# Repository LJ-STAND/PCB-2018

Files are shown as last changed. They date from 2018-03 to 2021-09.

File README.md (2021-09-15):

# PCB 2018

This repository contains the PCB design files for the LJ STAND 2018 robot. They were produced using Autodesk EAGLE.

**There are the following boards in the ```LJ STAND``` directory:**
- Encoder - this is a hall-sensor based encoder for the robot wheels. Each wheel has alternating polarity magnets that trigger the sensors.
- Gyro MPU9250 - this is a breakout board for a fusion of 3 MPU9250 sensors. This was done to compensate for drift
- Gyro - an older design of the IMU breakout board using a different sensor
- Laser Mount - mount for the laser in a light-gate module
- Light - a 48-sensor circular reflective-light sensor array, used for detecting the position of a white line
- Main - main processing board, housing the microcontrollers, camera, power supply, motor driver modules and IR sensors for the ball
- MPU9250 Adapter - can replace the IMU breakout board with a single off the shelf MPU9250 breakout
- Phototransitor Mount - mount for the phototransistor in a light-gate module

---------------------------------

<p align="center">
  
</p>

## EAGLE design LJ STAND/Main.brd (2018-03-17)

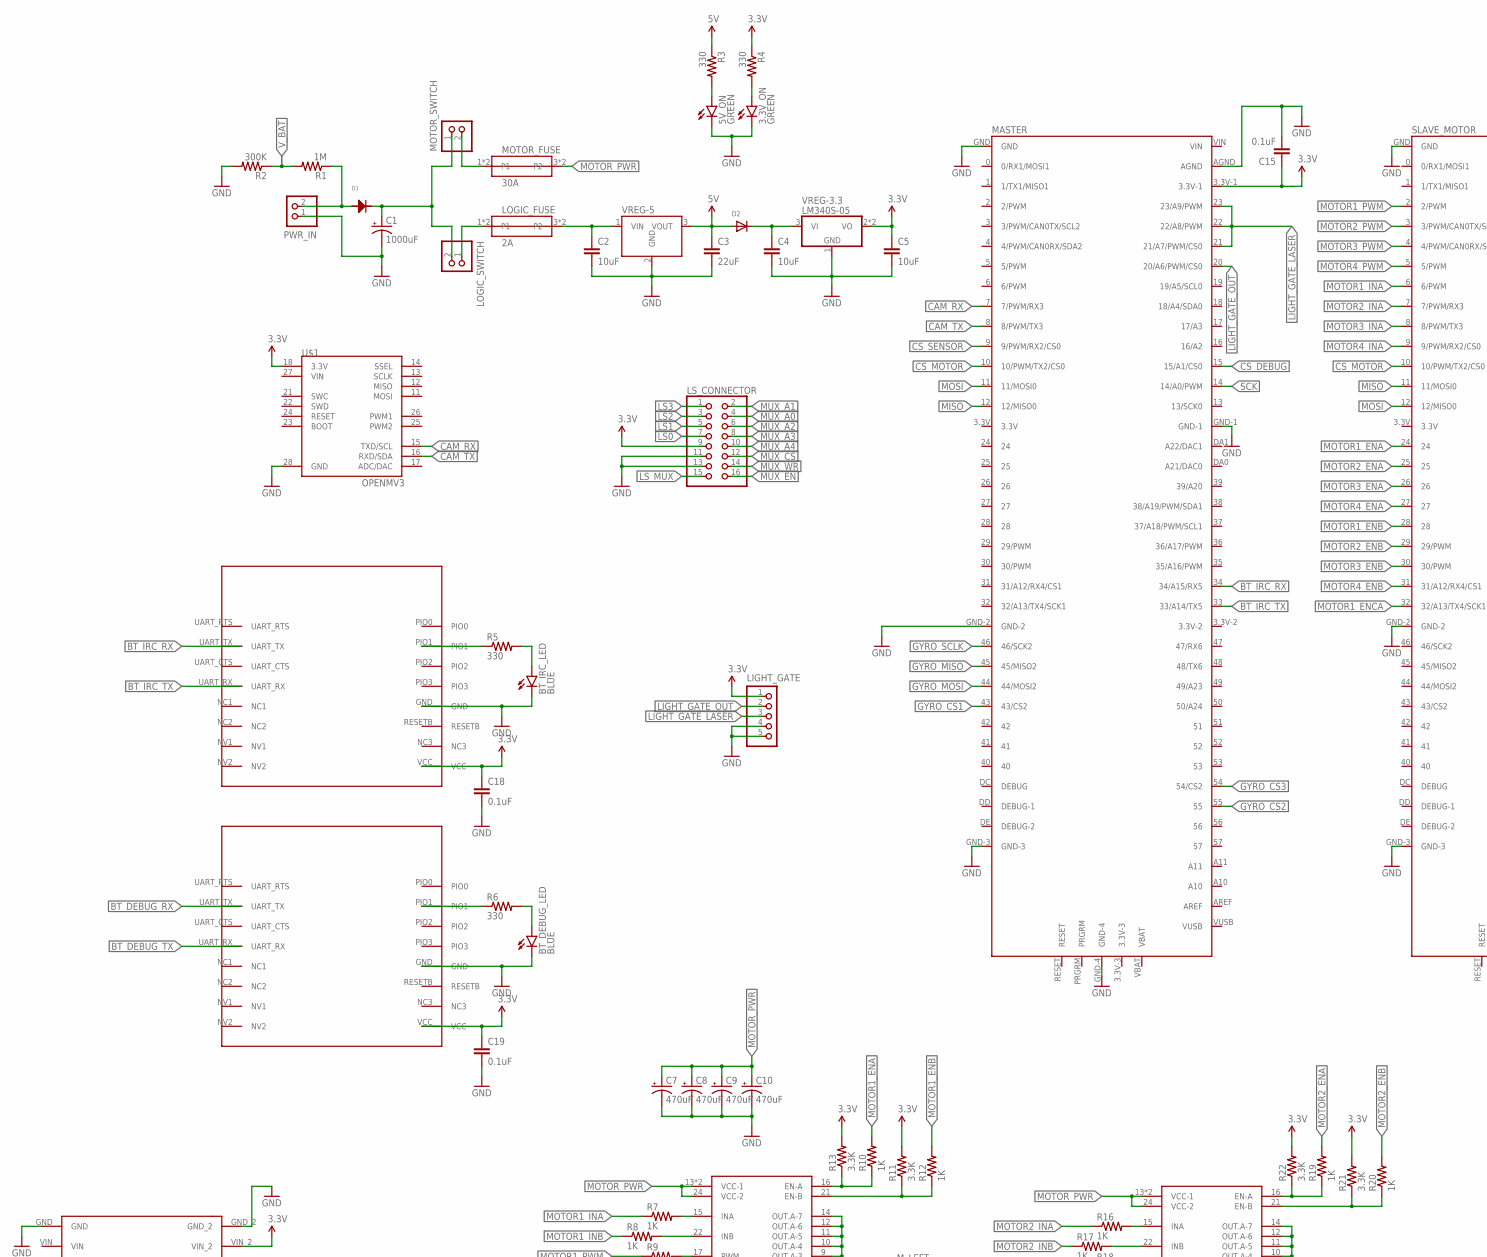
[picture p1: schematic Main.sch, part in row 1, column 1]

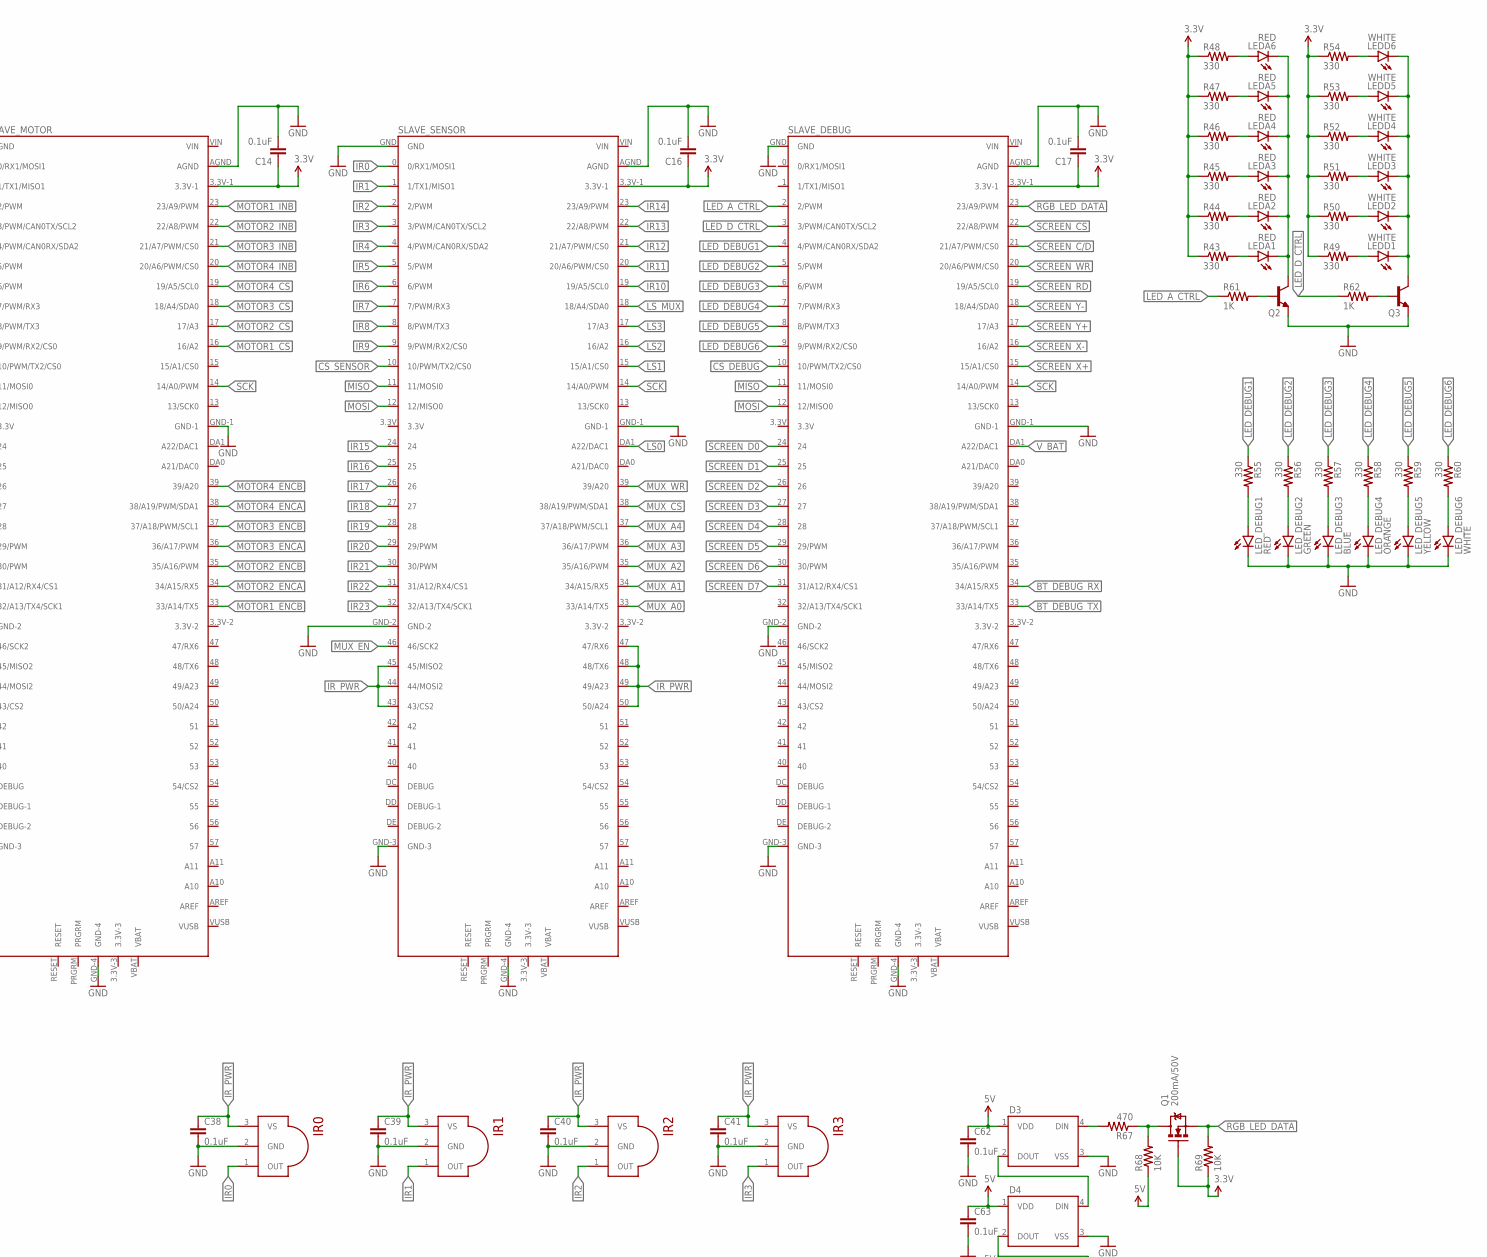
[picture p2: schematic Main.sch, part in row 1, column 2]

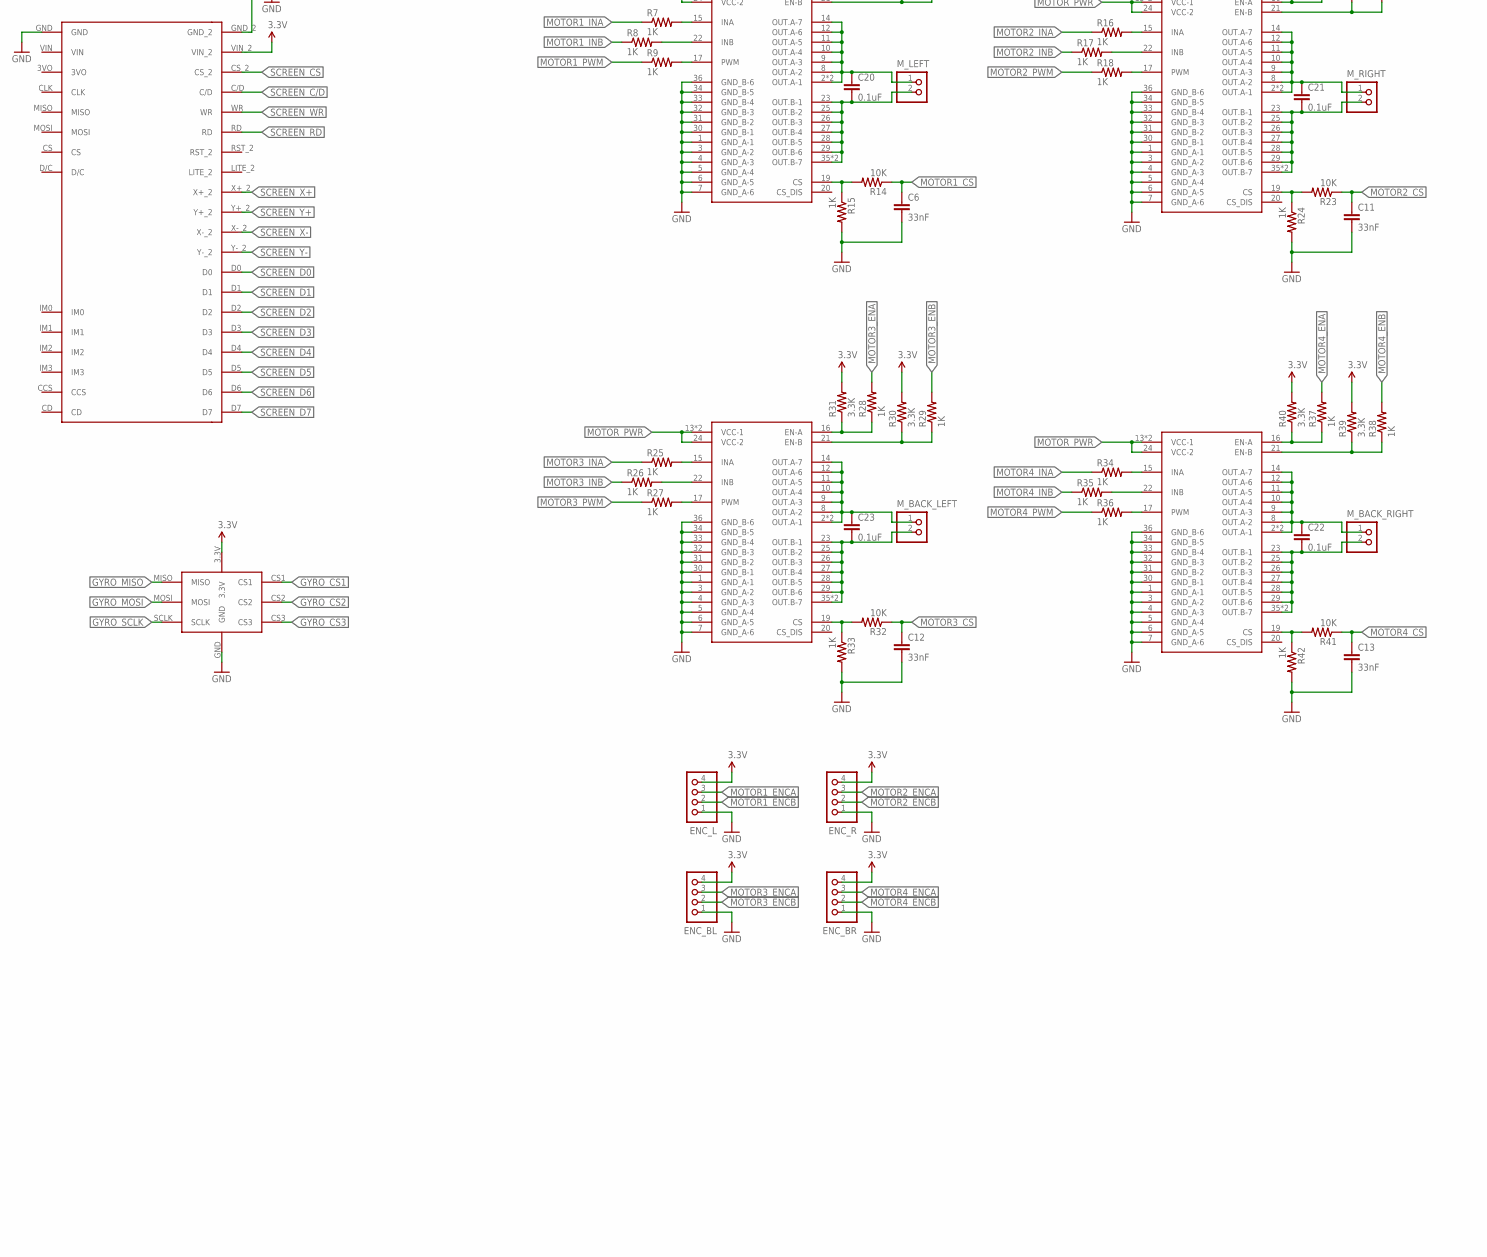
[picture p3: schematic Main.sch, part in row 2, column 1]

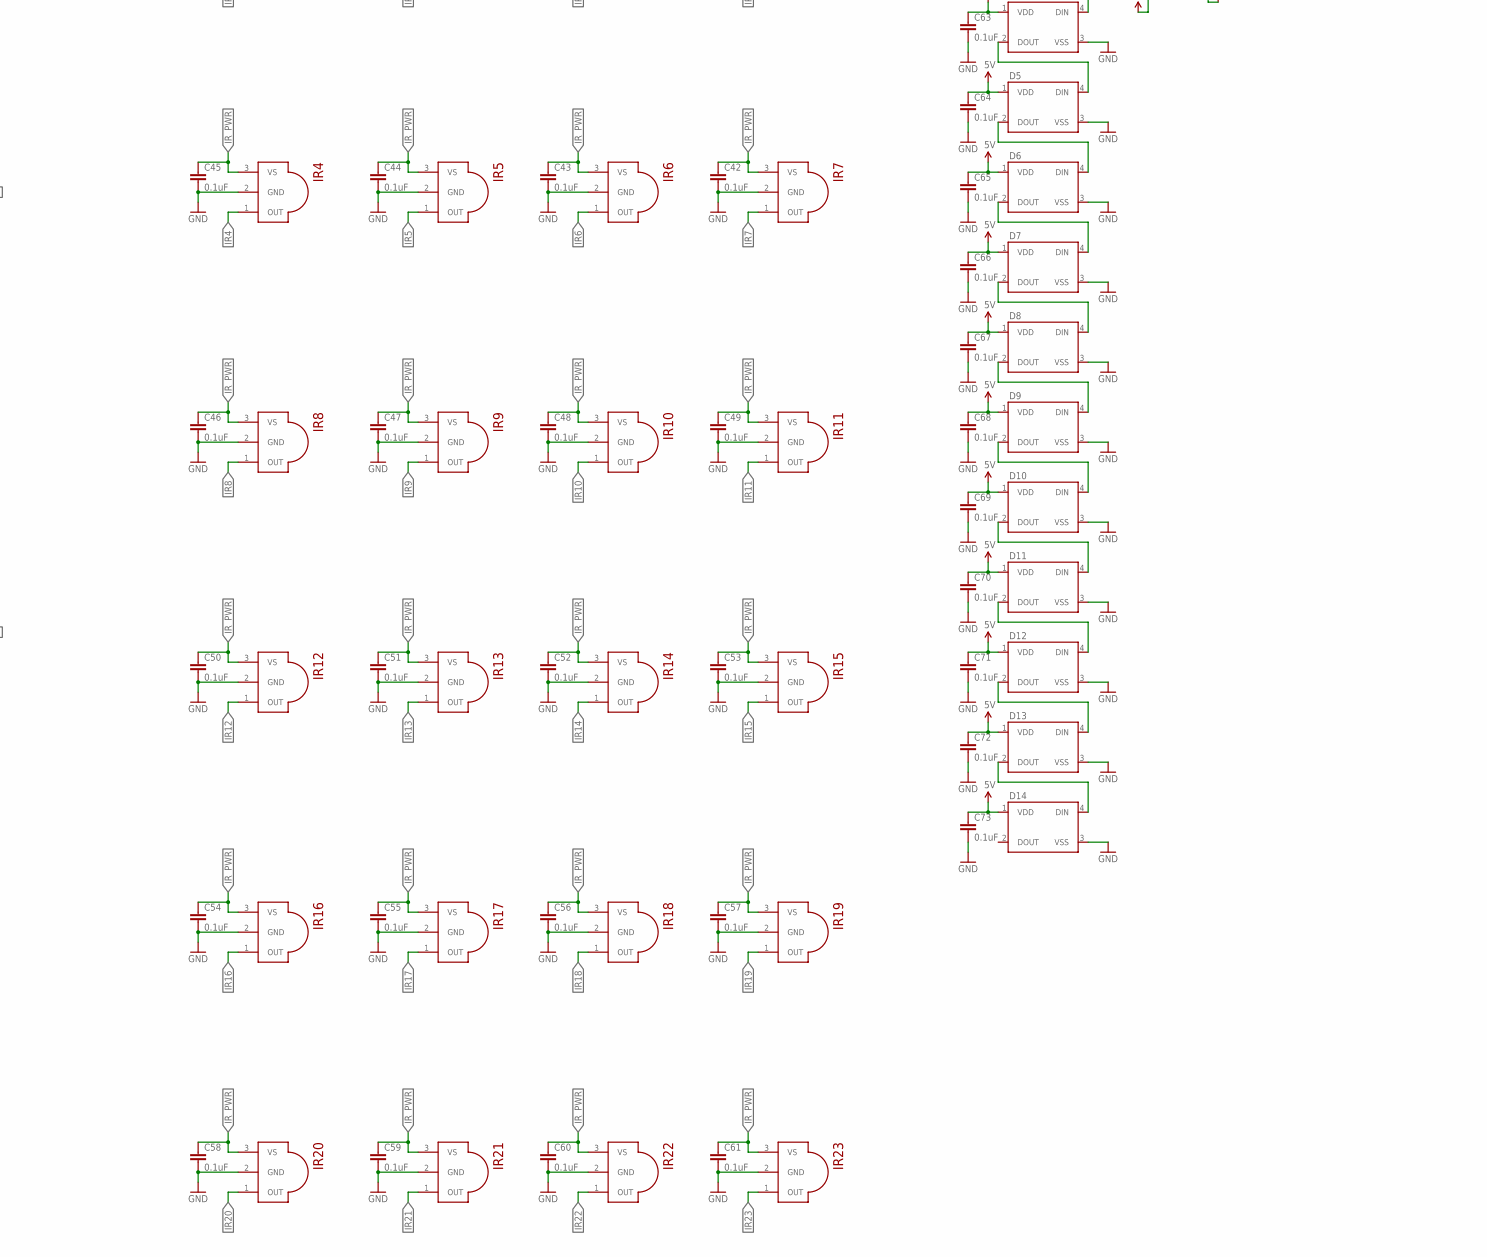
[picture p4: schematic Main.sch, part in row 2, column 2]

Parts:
3.3V_ON, 5V_ON: GREEN; LED-0603
BT_DEBUG: HM-11
BT_DEBUG_LED: BLUE; LED-0603
BT_IRC: HM-11
BT_IRC_LED: BLUE; LED-0603
C1: 1000uF; CPOL-RADIAL-1000UF-25V
C2, C4, C5: 10uF; 0805
C3: 22uF; 1206
C6, C11, C12, C13: 33nF; 0603-CAP
C7, C8, C9, C10: 470uF; E3,5-8
C14, C15, C16, C17, C18, C19, C20, C21, C22, C23, C38, C39, C40, C41, C42, C43, C44, C45, C46, C47, C48, C49, C50, C51, C52, C53, C54, C55, C56, C57, C58, C59, C60, C61, C62, C63, C64, C65, C66, C67, C68, C69, C70, C71, C72, C73: 0.1uF; 0603-CAP
D1: DIODE_D2PAK(TO-263AB); D2PAK(TO-263AB)
D2: DIODE_SOD-123FL; SOD-123FL
D3, D4, D5, D6, D7, D8, D9, D10, D11, D12, D13, D14: WS2812B
ENC_BL: B4B-PH-K-S
ENC_BR: B4B-PH-K-S
ENC_L: B4B-PH-K-S
ENC_R: B4B-PH-K-S
IR0, IR1, IR2, IR3, IR4, IR5, IR6, IR7, IR8, IR9, IR10, IR11, IR12, IR13, IR14, IR15, IR16, IR17, IR18, IR19, IR20, IR21, IR22, IR23: TSSP58038
LEDA1, LEDA2, LEDA3, LEDA4, LEDA5, LEDA6: RED; LED-0603
LEDD1, LEDD2, LEDD3, LEDD4, LEDD5, LEDD6: WHITE; LED-0603
LED_DEBUG1: RED; LED-0603
LED_DEBUG2: GREEN; LED-0603
LED_DEBUG3: BLUE; LED-0603
LED_DEBUG4: ORANGE; LED-0603
LED_DEBUG5: YELLOW; LED-0603
LED_DEBUG6: WHITE; LED-0603
LIGHT_GATE: B5B-PH-K-S
LOGIC_FUSE: 2A; 3568-FUSEHOLDER
LOGIC_SWITCH: B2P-VH
LS_CONNECTOR: PINHD-2X8SMT; 2X08_SMT
MASTER: TEENSY-3.5
MOTOR_FUSE: 30A; 3568-FUSEHOLDER
MOTOR_SWITCH: B2P-VH
M_BACK_LEFT: B2P-VH
M_BACK_RIGHT: B2P-VH
M_LEFT: B2P-VH
M_RIGHT: B2P-VH
P1, P2, P3, P4: SOP50P1030X247-36N
PWR_IN: B2P-VH
Q1: 200mA/50V; SOT23-3
Q2, Q3: TRANSISTOR_NPNSOT23-3; SOT23-3
R1: 1M; 0603-RES
R2: 300K; 0603-RES
R3, R4, R5, R6, R43, R44, R45, R46, R47, R48, R49, R50, R51, R52, R53, R54, R55, R56, R57, R58, R59, R60: 330; 0603-RES
R7, R8, R9, R10, R12, R15, R16, R17, R18, R19, R20, R24, R25, R26, R27, R28, R29, R33, R34, R35, R36, R37, R38, R42, R61, R62: 1K; 0603-RES
R11, R13, R21, R22, R30, R31, R39, R40: 3.3K; 0603-RES
R14, R23, R32, R41, R68, R69: 10K; 0603-RES
R67: 470; 0603-RES
SCREEN: ADAFRUIT-2.4-TFT
SLAVE_DEBUG: TEENSY-3.5
SLAVE_MOTOR: TEENSY-3.5
SLAVE_SENSOR: TEENSY-3.5
U$1: OPENMV3
U$2: GYRO
VREG-3.3: LM340S-05; TO263-3
VREG-5: V78-2000

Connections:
3.3V: BT_DEBUG.VCC, BT_IRC.VCC, C5.1, C14.1, C15.1, C16.1, C17.1, C18.1, C19.1, ENC_BL.4, ENC_BR.4, ENC_L.4, ENC_R.4, LIGHT_GATE.1, LS_CONNECTOR.9, MASTER.3.3V-1, Q1.1 (G), R4.1, R11.2, R13.2, R21.2, R22.2, R30.2, R31.2, R39.2, R40.2, R43.1, R44.1, R45.1, R46.1, R47.1, R48.1, R49.1, R50.1, R51.1, R52.1, R53.1, R54.1, R69.1, SCREEN.VIN_2, SLAVE_DEBUG.3.3V-1, SLAVE_MOTOR.3.3V-1, SLAVE_SENSOR.3.3V-1, U$1.18 (3.3V), U$2.3.3V, VREG-3.3.2 (VO), VREG-3.3.TAB (VO)
5V: C3.1, C62.1, C63.1, C64.1, C65.1, C66.1, C67.1, C68.1, C69.1, C70.1, C71.1, C72.1, C73.1, D2.A, D3.1 (VDD), D4.1 (VDD), D5.1 (VDD), D6.1 (VDD), D7.1 (VDD), D8.1 (VDD), D9.1 (VDD), D10.1 (VDD), D11.1 (VDD), D12.1 (VDD), D13.1 (VDD), D14.1 (VDD), R3.1, R68.1, VREG-5.3 (VOUT)
BT_DEBUG_RX: BT_DEBUG.UART_TX, SLAVE_DEBUG.34 (34/A15/RX5)
BT_DEBUG_TX: BT_DEBUG.UART_RX, SLAVE_DEBUG.33 (33/A14/TX5)
BT_IRC_RX: BT_IRC.UART_TX, MASTER.34 (34/A15/RX5)
BT_IRC_TX: BT_IRC.UART_RX, MASTER.33 (33/A14/TX5)
CAM_RX: MASTER.7 (7/PWM/RX3), U$1.15 (TXD/SCL)
CAM_TX: MASTER.8 (8/PWM/TX3), U$1.16 (RXD/SDA)
CS_DEBUG: MASTER.15 (15/A1/CS0), SLAVE_DEBUG.10 (10/PWM/TX2/CS0)
CS_MOTOR: MASTER.10 (10/PWM/TX2/CS0), SLAVE_MOTOR.10 (10/PWM/TX2/CS0)
CS_SENSOR: MASTER.9 (9/PWM/RX2/CS0), SLAVE_SENSOR.10 (10/PWM/TX2/CS0)
GND: 3.3V_ON.C, 5V_ON.C, BT_DEBUG.GND, BT_DEBUG_LED.C, BT_IRC.GND, BT_IRC_LED.C, C1.-, C2.2, C3.2, C4.2, C5.2, C6.2, C7.-, C8.-, C9.-, C10.-, C11.2, C12.2, C13.2, C14.2, C15.2, C16.2, C17.2, C18.2, C19.2, C38.2, C39.2, C40.2, C41.2, C42.2, C43.2, C44.2, C45.2, C46.2, C47.2, C48.2, C49.2, C50.2, C51.2, C52.2, C53.2, C54.2, C55.2, C56.2, C57.2, C58.2, C59.2, C60.2, C61.2, C62.2, C63.2, C64.2, C65.2, C66.2, C67.2, C68.2, C69.2, C70.2, C71.2, C72.2, C73.2, D3.3 (VSS), D4.3 (VSS), D5.3 (VSS), D6.3 (VSS), D7.3 (VSS), D8.3 (VSS), D9.3 (VSS), D10.3 (VSS), D11.3 (VSS), D12.3 (VSS), D13.3 (VSS), D14.3 (VSS), ENC_BL.1, ENC_BR.1, ENC_L.1, ENC_R.1, IR0.2 (GND), IR1.2 (GND), IR2.2 (GND), IR3.2 (GND), IR4.2 (GND), IR5.2 (GND), IR6.2 (GND), IR7.2 (GND), IR8.2 (GND), IR9.2 (GND), IR10.2 (GND), IR11.2 (GND), IR12.2 (GND), IR13.2 (GND), IR14.2 (GND), IR15.2 (GND), IR16.2 (GND), IR17.2 (GND), IR18.2 (GND), IR19.2 (GND), IR20.2 (GND), IR21.2 (GND), IR22.2 (GND), IR23.2 (GND), LED_DEBUG1.C, LED_DEBUG2.C, LED_DEBUG3.C, LED_DEBUG4.C, LED_DEBUG5.C, LED_DEBUG6.C, LIGHT_GATE.4, LIGHT_GATE.5, LS_CONNECTOR.11, LS_CONNECTOR.13, MASTER.AGND, MASTER.GND, MASTER.GND-1, MASTER.GND-2, MASTER.GND-3, MASTER.GND-4, P1.1 (GND_A-1), P1.3 (GND_A-2), P1.4 (GND_A-3), P1.5 (GND_A-4), P1.6 (GND_A-5), P1.7 (GND_A-6), P1.30 (GND_B-1), P1.31 (GND_B-2), P1.32 (GND_B-3), P1.33 (GND_B-4), P1.34 (GND_B-5), P1.36 (GND_B-6), P2.1 (GND_A-1), P2.3 (GND_A-2), P2.4 (GND_A-3), P2.5 (GND_A-4), P2.6 (GND_A-5), P2.7 (GND_A-6), P2.30 (GND_B-1), P2.31 (GND_B-2), P2.32 (GND_B-3), P2.33 (GND_B-4), P2.34 (GND_B-5), P2.36 (GND_B-6), P3.1 (GND_A-1), P3.3 (GND_A-2), P3.4 (GND_A-3), P3.5 (GND_A-4), P3.6 (GND_A-5), P3.7 (GND_A-6), P3.30 (GND_B-1), P3.31 (GND_B-2), P3.32 (GND_B-3), P3.33 (GND_B-4), P3.34 (GND_B-5), P3.36 (GND_B-6), P4.1 (GND_A-1), P4.3 (GND_A-2), P4.4 (GND_A-3), P4.5 (GND_A-4), P4.6 (GND_A-5), P4.7 (GND_A-6), P4.30 (GND_B-1), P4.31 (GND_B-2), P4.32 (GND_B-3), P4.33 (GND_B-4), P4.34 (GND_B-5), P4.36 (GND_B-6), PWR_IN.1, Q2.2 (E), Q3.2 (E), R2.2, R15.2, R24.2, R33.2, R42.2, SCREEN.GND, SCREEN.GND_2, SLAVE_DEBUG.AGND, SLAVE_DEBUG.GND, SLAVE_DEBUG.GND-1, SLAVE_DEBUG.GND-2, SLAVE_DEBUG.GND-3, SLAVE_DEBUG.GND-4, SLAVE_MOTOR.AGND, SLAVE_MOTOR.GND, SLAVE_MOTOR.GND-1, SLAVE_MOTOR.GND-2, SLAVE_MOTOR.GND-3, SLAVE_MOTOR.GND-4, SLAVE_SENSOR.AGND, SLAVE_SENSOR.GND, SLAVE_SENSOR.GND-1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
GYRO_CS1: MASTER.43 (43/CS2), U$2.CS1
GYRO_CS2: MASTER.55, U$2.CS2
GYRO_CS3: MASTER.54 (54/CS2), U$2.CS3
GYRO_MISO: MASTER.45 (45/MISO2), U$2.MISO
GYRO_MOSI: MASTER.44 (44/MOSI2), U$2.MOSI
GYRO_SCLK: MASTER.46 (46/SCK2), U$2.SCLK
IR0: IR0.1 (OUT), SLAVE_SENSOR.0 (0/RX1/MOSI1)
IR1: IR1.1 (OUT), SLAVE_SENSOR.1 (1/TX1/MISO1)
IR2: IR2.1 (OUT), SLAVE_SENSOR.2 (2/PWM)
IR3: IR3.1 (OUT), SLAVE_SENSOR.3 (3/PWM/CAN0TX/SCL2)
IR4: IR4.1 (OUT), SLAVE_SENSOR.4 (4/PWM/CAN0RX/SDA2)
IR5: IR5.1 (OUT), SLAVE_SENSOR.5 (5/PWM)
IR6: IR6.1 (OUT), SLAVE_SENSOR.6 (6/PWM)
IR7: IR7.1 (OUT), SLAVE_SENSOR.7 (7/PWM/RX3)
IR8: IR8.1 (OUT), SLAVE_SENSOR.8 (8/PWM/TX3)
IR9: IR9.1 (OUT), SLAVE_SENSOR.9 (9/PWM/RX2/CS0)
IR10: IR10.1 (OUT), SLAVE_SENSOR.19 (19/A5/SCL0)
IR11: IR11.1 (OUT), SLAVE_SENSOR.20 (20/A6/PWM/CS0)
IR12: IR12.1 (OUT), SLAVE_SENSOR.21 (21/A7/PWM/CS0)
IR13: IR13.1 (OUT), SLAVE_SENSOR.22 (22/A8/PWM)
IR14: IR14.1 (OUT), SLAVE_SENSOR.23 (23/A9/PWM)
IR15: IR15.1 (OUT), SLAVE_SENSOR.24
IR16: IR16.1 (OUT), SLAVE_SENSOR.25
IR17: IR17.1 (OUT), SLAVE_SENSOR.26
IR18: IR18.1 (OUT), SLAVE_SENSOR.27
IR19: IR19.1 (OUT), SLAVE_SENSOR.28
IR20: IR20.1 (OUT), SLAVE_SENSOR.29 (29/PWM)
IR21: IR21.1 (OUT), SLAVE_SENSOR.30 (30/PWM)
IR22: IR22.1 (OUT), SLAVE_SENSOR.31 (31/A12/RX4/CS1)
IR23: IR23.1 (OUT), SLAVE_SENSOR.32 (32/A13/TX4/SCK1)
IR_PWR: C38.1, C39.1, C40.1, C41.1, C42.1, C43.1, C44.1, C45.1, C46.1, C47.1, C48.1, C49.1, C50.1, C51.1, C52.1, C53.1, C54.1, C55.1, C56.1, C57.1, C58.1, C59.1, C60.1, C61.1, IR0.3 (VS), IR1.3 (VS), IR2.3 (VS), IR3.3 (VS), IR4.3 (VS), IR5.3 (VS), IR6.3 (VS), IR7.3 (VS), IR8.3 (VS), IR9.3 (VS), IR10.3 (VS), IR11.3 (VS), IR12.3 (VS), IR13.3 (VS), IR14.3 (VS), IR15.3 (VS), IR16.3 (VS), IR17.3 (VS), IR18.3 (VS), IR19.3 (VS), IR20.3 (VS), IR21.3 (VS), IR22.3 (VS), IR23.3 (VS), SLAVE_SENSOR.43 (43/CS2), SLAVE_SENSOR.44 (44/MOSI2), SLAVE_SENSOR.45 (45/MISO2), SLAVE_SENSOR.47 (47/RX6), SLAVE_SENSOR.48 (48/TX6), SLAVE_SENSOR.49 (49/A23), SLAVE_SENSOR.50 (50/A24)
LED_A_CTRL: R61.1, SLAVE_DEBUG.2 (2/PWM)
LED_DEBUG1: R55.1, SLAVE_DEBUG.4 (4/PWM/CAN0RX/SDA2)
LED_DEBUG2: R56.1, SLAVE_DEBUG.5 (5/PWM)
LED_DEBUG3: R57.1, SLAVE_DEBUG.6 (6/PWM)
LED_DEBUG4: R58.1, SLAVE_DEBUG.7 (7/PWM/RX3)
LED_DEBUG5: R59.1, SLAVE_DEBUG.8 (8/PWM/TX3)
LED_DEBUG6: R60.1, SLAVE_DEBUG.9 (9/PWM/RX2/CS0)
LED_D_CTRL: R62.1, SLAVE_DEBUG.3 (3/PWM/CAN0TX/SCL2)
LIGHT_GATE_LASER: LIGHT_GATE.3, MASTER.21 (21/A7/PWM/CS0), MASTER.22 (22/A8/PWM), MASTER.23 (23/A9/PWM)
LIGHT_GATE_OUT: LIGHT_GATE.2, MASTER.20 (20/A6/PWM/CS0)
LS0: LS_CONNECTOR.7, SLAVE_SENSOR.DA1 (A22/DAC1)
LS1: LS_CONNECTOR.5, SLAVE_SENSOR.15 (15/A1/CS0)
LS2: LS_CONNECTOR.3, SLAVE_SENSOR.16 (16/A2)
LS3: LS_CONNECTOR.1, SLAVE_SENSOR.17 (17/A3)
LS_MUX: LS_CONNECTOR.15, SLAVE_SENSOR.18 (18/A4/SDA0)
MISO: MASTER.12 (12/MISO0), SLAVE_DEBUG.11 (11/MOSI0), SLAVE_MOTOR.11 (11/MOSI0), SLAVE_SENSOR.11 (11/MOSI0)
MOSI: MASTER.11 (11/MOSI0), SLAVE_DEBUG.12 (12/MISO0), SLAVE_MOTOR.12 (12/MISO0), SLAVE_SENSOR.12 (12/MISO0)
MOTOR1_CS: C6.1, R14.1, SLAVE_MOTOR.16 (16/A2)
MOTOR1_ENA: R10.2, SLAVE_MOTOR.24
MOTOR1_ENB: R12.2, SLAVE_MOTOR.28
MOTOR1_ENCA: ENC_L.3, SLAVE_MOTOR.32 (32/A13/TX4/SCK1)
MOTOR1_ENCB: ENC_L.2, SLAVE_MOTOR.33 (33/A14/TX5)
MOTOR1_INA: R7.1, SLAVE_MOTOR.6 (6/PWM)
MOTOR1_INB: R8.1, SLAVE_MOTOR.23 (23/A9/PWM)
MOTOR1_OUTA: C20.1, M_LEFT.1, P1.2 (OUT.A-1), P1.8 (OUT.A-2), P1.9 (OUT.A-3), P1.10 (OUT.A-4), P1.11 (OUT.A-5), P1.12 (OUT.A-6), P1.14 (OUT.A-7), P1.SLUG2 (OUT.A-1)
MOTOR1_OUTB: C20.2, M_LEFT.2, P1.23 (OUT.B-1), P1.25 (OUT.B-2), P1.26 (OUT.B-3), P1.27 (OUT.B-4), P1.28 (OUT.B-5), P1.29 (OUT.B-6), P1.35 (OUT.B-7), P1.SLUG3 (OUT.B-7)
MOTOR1_PWM: R9.1, SLAVE_MOTOR.2 (2/PWM)
MOTOR2_CS: C11.1, R23.1, SLAVE_MOTOR.17 (17/A3)
MOTOR2_ENA: R19.2, SLAVE_MOTOR.25
MOTOR2_ENB: R20.2, SLAVE_MOTOR.29 (29/PWM)
MOTOR2_ENCA: ENC_R.3, SLAVE_MOTOR.34 (34/A15/RX5)
MOTOR2_ENCB: ENC_R.2, SLAVE_MOTOR.35 (35/A16/PWM)
MOTOR2_INA: R16.1, SLAVE_MOTOR.7 (7/PWM/RX3)
MOTOR2_INB: R17.1, SLAVE_MOTOR.22 (22/A8/PWM)
MOTOR2_OUTA: C21.1, M_RIGHT.1, P2.2 (OUT.A-1), P2.8 (OUT.A-2), P2.9 (OUT.A-3), P2.10 (OUT.A-4), P2.11 (OUT.A-5), P2.12 (OUT.A-6), P2.14 (OUT.A-7), P2.SLUG2 (OUT.A-1)
MOTOR2_OUTB: C21.2, M_RIGHT.2, P2.23 (OUT.B-1), P2.25 (OUT.B-2), P2.26 (OUT.B-3), P2.27 (OUT.B-4), P2.28 (OUT.B-5), P2.29 (OUT.B-6), P2.35 (OUT.B-7), P2.SLUG3 (OUT.B-7)
MOTOR2_PWM: R18.1, SLAVE_MOTOR.3 (3/PWM/CAN0TX/SCL2)
MOTOR3_CS: C12.1, R32.1, SLAVE_MOTOR.18 (18/A4/SDA0)
MOTOR3_ENA: R28.2, SLAVE_MOTOR.26
MOTOR3_ENB: R29.2, SLAVE_MOTOR.30 (30/PWM)
MOTOR3_ENCA: ENC_BL.3, SLAVE_MOTOR.36 (36/A17/PWM)
MOTOR3_ENCB: ENC_BL.2, SLAVE_MOTOR.37 (37/A18/PWM/SCL1)
MOTOR3_INA: R25.1, SLAVE_MOTOR.8 (8/PWM/TX3)
MOTOR3_INB: R26.1, SLAVE_MOTOR.21 (21/A7/PWM/CS0)
MOTOR3_OUTA: C23.1, M_BACK_LEFT.1, P3.2 (OUT.A-1), P3.8 (OUT.A-2), P3.9 (OUT.A-3), P3.10 (OUT.A-4), P3.11 (OUT.A-5), P3.12 (OUT.A-6), P3.14 (OUT.A-7), P3.SLUG2 (OUT.A-1)
MOTOR3_OUTB: C23.2, M_BACK_LEFT.2, P3.23 (OUT.B-1), P3.25 (OUT.B-2), P3.26 (OUT.B-3), P3.27 (OUT.B-4), P3.28 (OUT.B-5), P3.29 (OUT.B-6), P3.35 (OUT.B-7), P3.SLUG3 (OUT.B-7)
MOTOR3_PWM: R27.1, SLAVE_MOTOR.4 (4/PWM/CAN0RX/SDA2)
MOTOR4_CS: C13.1, R41.1, SLAVE_MOTOR.19 (19/A5/SCL0)
MOTOR4_ENA: R37.2, SLAVE_MOTOR.27
MOTOR4_ENB: R38.2, SLAVE_MOTOR.31 (31/A12/RX4/CS1)
MOTOR4_ENCA: ENC_BR.3, SLAVE_MOTOR.38 (38/A19/PWM/SDA1)
MOTOR4_ENCB: ENC_BR.2, SLAVE_MOTOR.39 (39/A20)
MOTOR4_INA: R34.1, SLAVE_MOTOR.9 (9/PWM/RX2/CS0)
MOTOR4_INB: R35.1, SLAVE_MOTOR.20 (20/A6/PWM/CS0)
MOTOR4_OUTA: C22.1, M_BACK_RIGHT.1, P4.2 (OUT.A-1), P4.8 (OUT.A-2), P4.9 (OUT.A-3), P4.10 (OUT.A-4), P4.11 (OUT.A-5), P4.12 (OUT.A-6), P4.14 (OUT.A-7), P4.SLUG2 (OUT.A-1)
MOTOR4_OUTB: C22.2, M_BACK_RIGHT.2, P4.23 (OUT.B-1), P4.25 (OUT.B-2), P4.26 (OUT.B-3), P4.27 (OUT.B-4), P4.28 (OUT.B-5), P4.29 (OUT.B-6), P4.35 (OUT.B-7), P4.SLUG3 (OUT.B-7)
MOTOR4_PWM: R36.1, SLAVE_MOTOR.5 (5/PWM)
MOTOR_PWR: C7.+, C8.+, C9.+, C10.+, MOTOR_FUSE.3 (P2), MOTOR_FUSE.4 (P2), P1.13 (VCC-1), P1.24 (VCC-2), P1.SLUG1 (VCC-1), P2.13 (VCC-1), P2.24 (VCC-2), P2.SLUG1 (VCC-1), P3.13 (VCC-1), P3.24 (VCC-2), P3.SLUG1 (VCC-1), P4.13 (VCC-1), P4.24 (VCC-2), P4.SLUG1 (VCC-1)
MUX_A0: LS_CONNECTOR.4, SLAVE_SENSOR.33 (33/A14/TX5)
MUX_A1: LS_CONNECTOR.2, SLAVE_SENSOR.34 (34/A15/RX5)
MUX_A2: LS_CONNECTOR.6, SLAVE_SENSOR.35 (35/A16/PWM)
MUX_A3: LS_CONNECTOR.8, SLAVE_SENSOR.36 (36/A17/PWM)
MUX_A4: LS_CONNECTOR.10, SLAVE_SENSOR.37 (37/A18/PWM/SCL1)
MUX_CS: LS_CONNECTOR.12, SLAVE_SENSOR.38 (38/A19/PWM/SDA1)
MUX_EN: LS_CONNECTOR.16, SLAVE_SENSOR.46 (46/SCK2)
MUX_WR: LS_CONNECTOR.14, SLAVE_SENSOR.39 (39/A20)
unnamed: MOTOR_FUSE.1, MOTOR_FUSE.2 (P1), MOTOR_SWITCH.2
unnamed: LOGIC_FUSE.1, LOGIC_FUSE.2 (P1), LOGIC_SWITCH.1
unnamed: LEDA1.A, R43.2
unnamed: LEDA2.A, R44.2
unnamed: LEDA3.A, R45.2
unnamed: LEDA4.A, R46.2
unnamed: LEDA5.A, R47.2
unnamed: LEDA6.A, R48.2
unnamed: LEDA1.C, LEDA2.C, LEDA3.C, LEDA4.C, LEDA5.C, LEDA6.C, Q2.3 (C)
unnamed: D1.A (ANODE), D1.NOP (ANODE), PWR_IN.2, R1.1
unnamed: C1.+, D1.C (CATHODE), LOGIC_SWITCH.2, MOTOR_SWITCH.1
unnamed: C2.1, LOGIC_FUSE.3 (P2), LOGIC_FUSE.4 (P2), VREG-5.1 (VIN)
unnamed: C4.1, D2.C, VREG-3.3.3 (VI)
unnamed: 5V_ON.A, R3.2
unnamed: 3.3V_ON.A, R4.2
unnamed: BT_IRC_LED.A, R5.2
unnamed: BT_IRC.PIO1, R5.1
unnamed: BT_DEBUG_LED.A, R6.2
unnamed: BT_DEBUG.PIO1, R6.1
unnamed: P1.16 (EN-A), R10.1, R13.1
unnamed: P1.22 (INB), R8.2
unnamed: P1.17 (PWM), R9.2
unnamed: P1.15 (INA), R7.2
unnamed: P1.21 (EN-B), R11.1, R12.1
unnamed: P1.19 (CS), R14.2, R15.1
unnamed: LEDD1.A, R49.2
unnamed: P2.15 (INA), R16.2
unnamed: P2.22 (INB), R17.2
unnamed: P2.17 (PWM), R18.2
unnamed: P2.16 (EN-A), R19.1, R22.1
unnamed: P2.21 (EN-B), R20.1, R21.1
unnamed: P2.19 (CS), R23.2, R24.1
unnamed: P3.15 (INA), R25.2
unnamed: P3.22 (INB), R26.2
unnamed: P3.17 (PWM), R27.2
unnamed: P3.16 (EN-A), R28.1, R31.1
unnamed: P3.21 (EN-B), R29.1, R30.1
unnamed: P3.19 (CS), R32.2, R33.1
unnamed: P4.15 (INA), R34.2
unnamed: P4.22 (INB), R35.2
unnamed: P4.17 (PWM), R36.2
unnamed: P4.16 (EN-A), R37.1, R40.1
unnamed: P4.21 (EN-B), R38.1, R39.1
unnamed: P4.19 (CS), R41.2, R42.1
unnamed: LEDD2.A, R50.2
unnamed: LEDD3.A, R51.2
unnamed: LEDD4.A, R52.2
unnamed: LEDD5.A, R53.2
unnamed: LEDD6.A, R54.2
unnamed: LEDD1.C, LEDD2.C, LEDD3.C, LEDD4.C, LEDD5.C, LEDD6.C, Q3.3 (C)
unnamed: LED_DEBUG1.A, R55.2
unnamed: LED_DEBUG2.A, R56.2
unnamed: LED_DEBUG3.A, R57.2
unnamed: LED_DEBUG4.A, R58.2
unnamed: LED_DEBUG5.A, R59.2
unnamed: LED_DEBUG6.A, R60.2
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

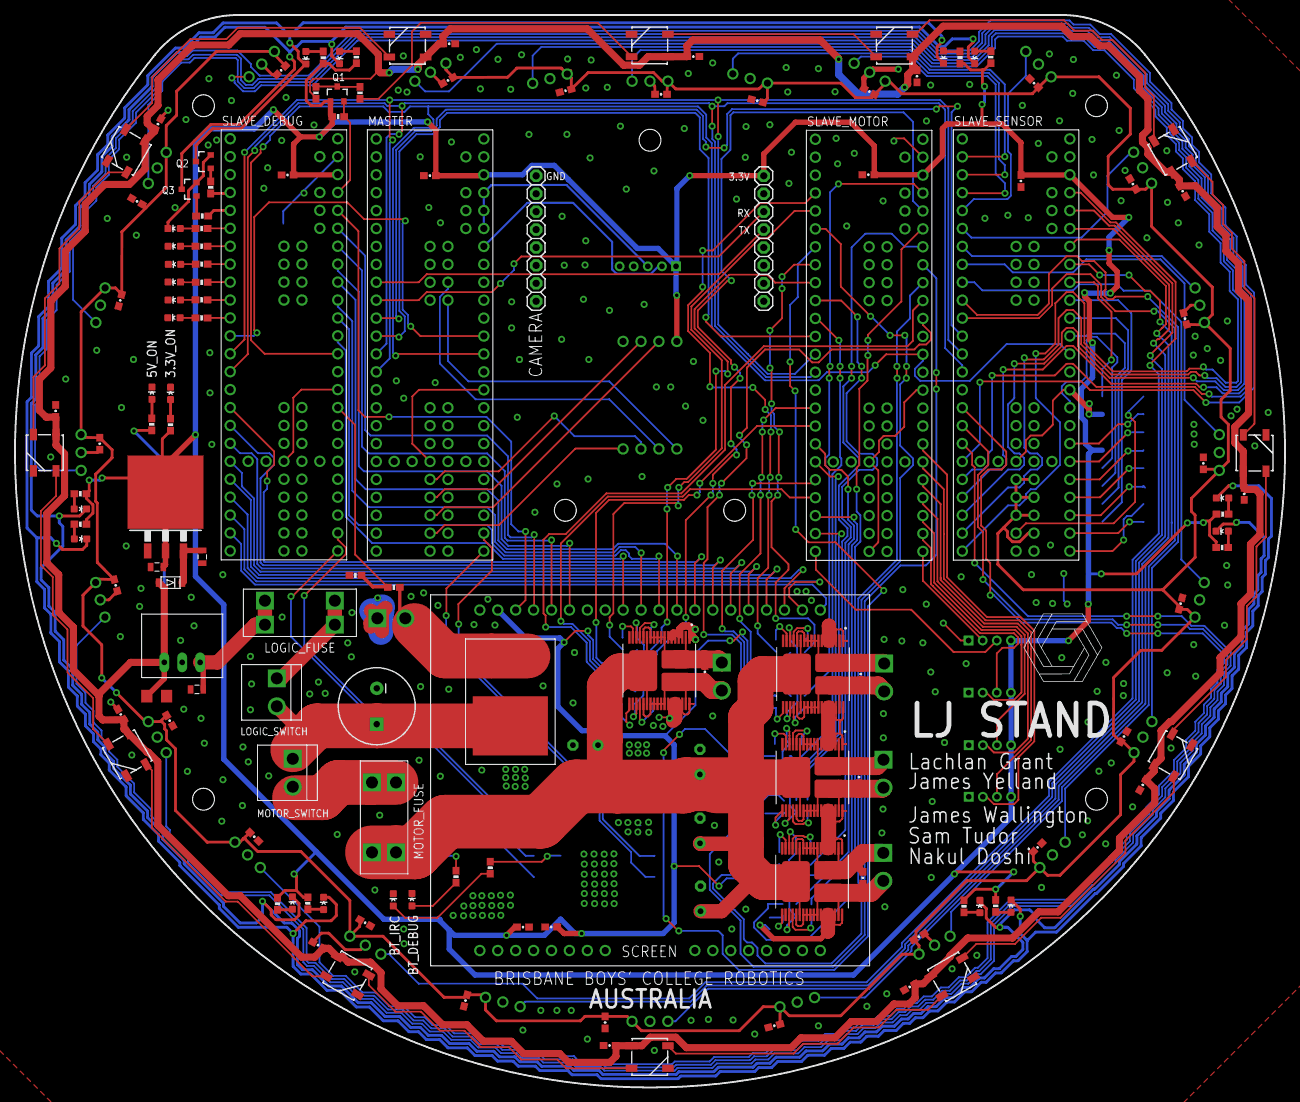
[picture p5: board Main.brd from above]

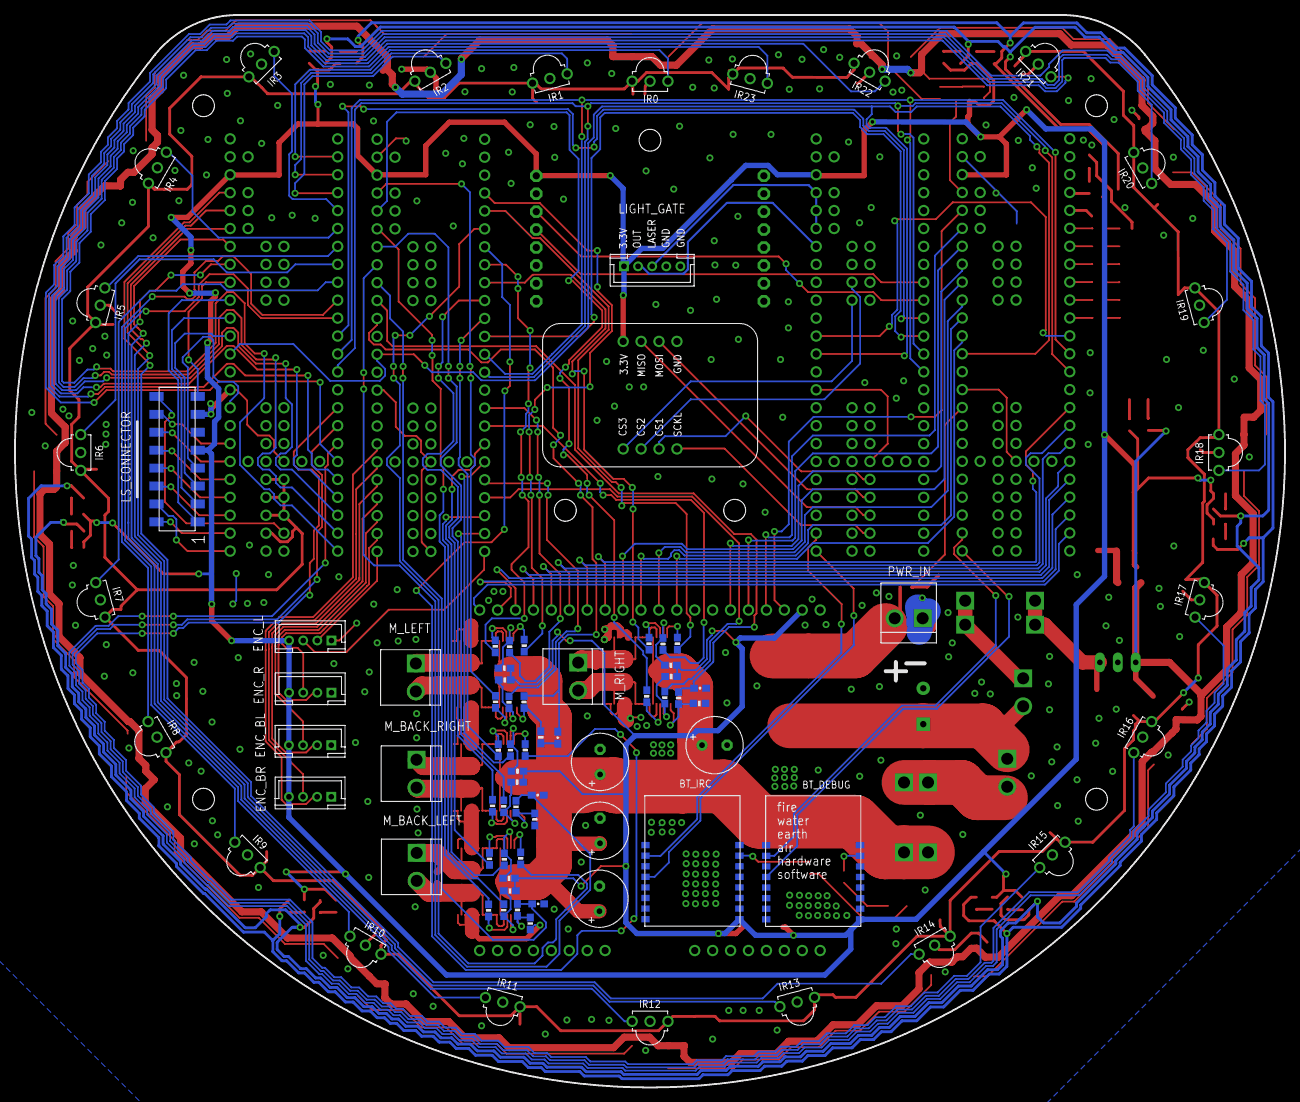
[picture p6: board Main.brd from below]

Board: 2 copper layers, 180.0 x 152.0 mm, 217 parts (82 on the bottom side), 199 nets.

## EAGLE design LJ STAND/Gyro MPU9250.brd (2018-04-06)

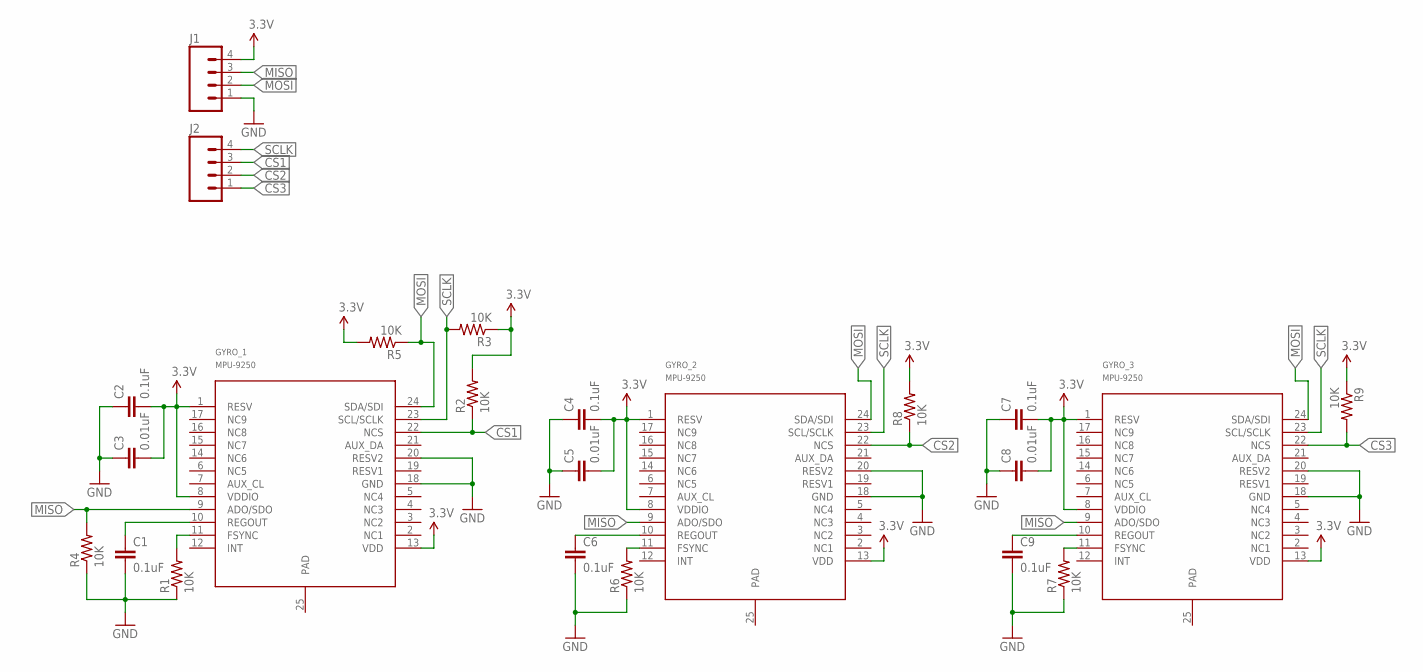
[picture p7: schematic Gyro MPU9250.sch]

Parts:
C1, C2, C4, C6, C7, C9: 0.1uF; 0603-CAP
C3, C5, C8: 0.01uF; 0603-CAP
GYRO_1, GYRO_2, GYRO_3: MPU-9250; LEAD-QFN24
J1, J2: M04PTH; 1X04
R1, R2, R3, R4, R5, R6, R7, R8, R9: 10K; 0603-RES

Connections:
3.3V: C2.2, C3.2, C4.2, C5.2, C7.2, C8.2, GYRO_1.1 (RESV), GYRO_1.8 (VDDIO), GYRO_1.13 (VDD), GYRO_2.1 (RESV), GYRO_2.8 (VDDIO), GYRO_2.13 (VDD), GYRO_3.1 (RESV), GYRO_3.8 (VDDIO), GYRO_3.13 (VDD), J1.4, R2.2, R3.1, R5.2, R8.2, R9.1
CS1: GYRO_1.22 (NCS), J2.3, R2.1
CS2: GYRO_2.22 (NCS), J2.2, R8.1
CS3: GYRO_3.22 (NCS), J2.1, R9.2
GND: C1.2, C2.1, C3.1, C4.1, C5.1, C6.2, C7.1, C8.1, C9.2, GYRO_1.18 (GND), GYRO_1.20 (RESV2), GYRO_2.18 (GND), GYRO_2.20 (RESV2), GYRO_3.18 (GND), GYRO_3.20 (RESV2), J1.1, R1.1, R4.1, R6.1, R7.1
MISO: GYRO_1.9 (ADO/SDO), GYRO_2.9 (ADO/SDO), GYRO_3.9 (ADO/SDO), J1.3, R4.2
MOSI: GYRO_1.24 (SDA/SDI), GYRO_2.24 (SDA/SDI), GYRO_3.24 (SDA/SDI), J1.2, R5.1
unnamed: C1.1, GYRO_1.10 (REGOUT)
unnamed: GYRO_1.11 (FSYNC), R1.2
unnamed: GYRO_3.11 (FSYNC), R7.2
unnamed: C6.1, GYRO_2.10 (REGOUT)
unnamed: C9.1, GYRO_3.10 (REGOUT)
unnamed: GYRO_2.11 (FSYNC), R6.2
SCLK: GYRO_1.23 (SCL/SCLK), GYRO_2.23 (SCL/SCLK), GYRO_3.23 (SCL/SCLK), J2.4, R3.2

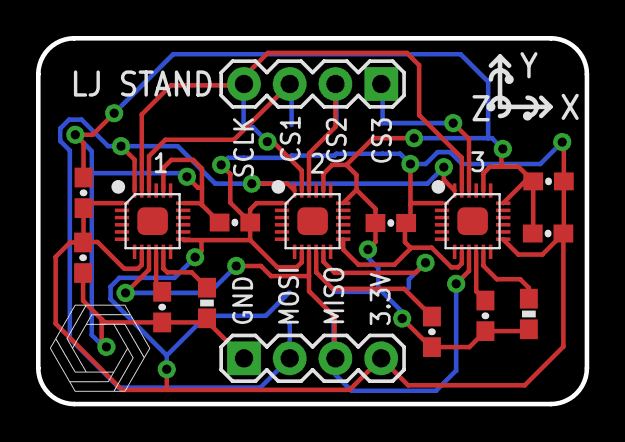
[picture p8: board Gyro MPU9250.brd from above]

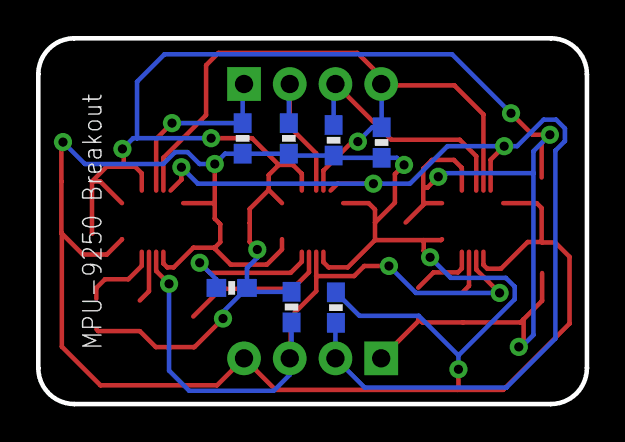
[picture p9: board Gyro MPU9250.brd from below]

Board: 2 copper layers, 30.5 x 20.3 mm, 23 parts (7 on the bottom side), 14 nets.

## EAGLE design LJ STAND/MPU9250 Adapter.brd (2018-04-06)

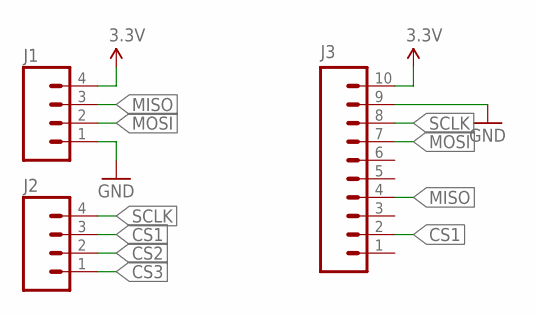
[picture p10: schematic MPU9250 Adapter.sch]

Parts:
J1, J2: M04PTH; 1X04
J3: M10SILK_FEMALE_PTH; 1X10

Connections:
3.3V: J1.4, J3.10
CS1: J2.3, J3.2
CS2: J2.2
CS3: J2.1
GND: J1.1, J3.9
MISO: J1.3, J3.4
MOSI: J1.2, J3.7
SCLK: J2.4, J3.8

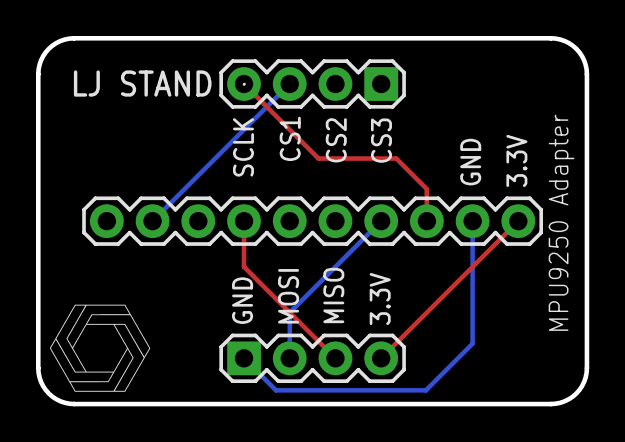
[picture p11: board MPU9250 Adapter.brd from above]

Board: 2 copper layers, 30.5 x 20.3 mm, 3 parts (0 on the bottom side), 6 nets.

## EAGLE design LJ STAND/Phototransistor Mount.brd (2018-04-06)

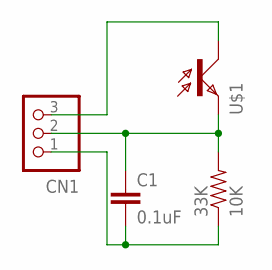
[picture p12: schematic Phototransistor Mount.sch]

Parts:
33K: 10K; 0603-RES
C1: 0.1uF; 0603-CAP
CN1: B3B-PH-K-S
U$1: ALS; SMD

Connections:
unnamed: CN1.3, U$1.C
unnamed: 33K.1, C1.2, CN1.1
OUT: 33K.2, C1.1, CN1.2, U$1.E

Board: 2 copper layers, 4 parts (0 on the bottom side), 3 nets, no tracks yet.

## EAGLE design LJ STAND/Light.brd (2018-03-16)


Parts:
C1, C2, C3, C4, C5, C6, C7, C8, C9, C10, C11, C12, C13, C14, C15, C16, C17, C18, C19, C20, C21, C22, C23, C24, C25, C26, C27, C28, C29, C30, C31, C32, C33, C34, C35, C36, C37: 0.1uF; 0603-CAP
C38: 10uF; 0805
D1, D2, D3, D4, D5, D6, D7, D8, D9, D10, D11, D12, D13, D14, D15, D16, D17, D18, D19, D20, D21, D22, D23, D24, D25, D26, D27, D28, D29, D30, D31, D32, D33, D34, D35, D36: LED0603; LED-0603
JP1: PINHD-2X8SMT; 2X08_SMT
LS0, LS1, LS2, LS3, LS4, LS5, LS6, LS7, LS8, LS9, LS10, LS11, LS12, LS13, LS14, LS15, LS16, LS17, LS18, LS19, LS20, LS21, LS22, LS23, LS24, LS25, LS26, LS27, LS28, LS29, LS30, LS31, LS32, LS33, LS34, LS35: ALS; SMD
R1, R3, R5, R7, R9, R11, R13, R15, R17, R19, R21, R23, R25, R27, R29, R31, R33, R35, R37, R39, R41, R43, R45, R47, R49, R51, R53, R55, R57, R59, R61, R63, R65, R67, R69, R71: 75K; 0603-RES
R2, R4, R6, R8, R10, R12, R14, R16, R18, R20, R22, R24, R26, R28, R30, R32, R34, R36, R38, R40, R42, R44, R46, R48, R50, R52, R54, R56, R58, R60, R62, R64, R66, R68, R70, R72: 75; 0603-RES
U$1: ADG732; QFP-7X7-48-NO-EXP

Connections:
3.3V: C37.2, C38.1, JP1.9, LS0.C, LS1.C, LS2.C, LS3.C, LS4.C, LS5.C, LS6.C, LS7.C, LS8.C, LS9.C, LS10.C, LS11.C, LS12.C, LS13.C, LS14.C, LS15.C, LS16.C, LS17.C, LS18.C, LS19.C, LS20.C, LS21.C, LS22.C, LS23.C, LS24.C, LS25.C, LS26.C, LS27.C, LS28.C, LS29.C, LS30.C, LS31.C, LS32.C, LS33.C, LS34.C, LS35.C, R2.2, R4.2, R6.2, R8.2, R10.2, R12.2, R14.2, R16.2, R18.2, R20.2, R22.2, R24.2, R26.2, R28.2, R30.2, R32.2, R34.2, R36.2, R38.2, R40.2, R42.2, R44.2, R46.2, R48.2, R50.2, R52.2, R54.2, R56.2, R58.2, R60.2, R62.2, R64.2, R66.2, R68.2, R70.2, R72.2, U$1.13 (VDD), U$1.14 (VDD_2)
A0: JP1.4, U$1.15 (A0)
A1: JP1.2, U$1.16 (A1)
A2: JP1.6, U$1.17 (A2)
A3: JP1.8, U$1.18 (A3)
A4: JP1.10, U$1.19 (A4)
CS: JP1.12, U$1.20 (CS)
EN: JP1.16, U$1.22 (EN)
GND: C1.2, C2.2, C3.2, C4.2, C5.2, C6.2, C7.2, C8.2, C9.2, C10.2, C11.2, C12.2, C13.2, C14.2, C15.2, C16.2, C17.2, C18.2, C19.2, C20.2, C21.2, C22.2, C23.2, C24.2, C25.2, C26.2, C27.2, C28.2, C29.2, C30.2, C31.2, C32.2, C33.2, C34.2, C35.2, C36.2, C37.1, C38.2, D1.C, D2.C, D3.C, D4.C, D5.C, D6.C, D7.C, D8.C, D9.C, D10.C, D11.C, D12.C, D13.C, D14.C, D15.C, D16.C, D17.C, D18.C, D19.C, D20.C, D21.C, D22.C, D23.C, D24.C, D25.C, D26.C, D27.C, D28.C, D29.C, D30.C, D31.C, D32.C, D33.C, D34.C, D35.C, D36.C, JP1.11, JP1.13, R1.1, R3.1, R5.1, R7.1, R9.1, R11.1, R13.1, R15.1, R17.1, R19.1, R21.1, R23.1, R25.1, R27.1, R29.1, R31.1, R33.1, R35.1, R37.1, R39.1, R41.1, R43.1, R45.1, R47.1, R49.1, R51.1, R53.1, R55.1, R57.1, R59.1, R61.1, R63.1, R65.1, R67.1, R69.1, R71.1, U$1.23 (GND), U$1.24 (VSS)
LS0: C13.1, JP1.7, LS0.E, R25.2
LS1: C14.1, JP1.5, LS1.E, R27.2
LS2: C15.1, JP1.3, LS2.E, R29.2
LS3: C16.1, JP1.1, LS3.E, R31.2
LS4: C1.1, LS4.E, R1.2, U$1.1 (S12)
LS5: C2.1, LS5.E, R3.2, U$1.2 (S11)
LS6: C3.1, LS6.E, R5.2, U$1.3 (S10)
LS7: C4.1, LS7.E, R7.2, U$1.4 (S9)
LS8: C5.1, LS8.E, R9.2, U$1.48 (S13)
LS9: C6.1, LS9.E, R11.2, U$1.47 (S14)
LS10: C7.1, LS10.E, R13.2, U$1.46 (S15)
LS11: C8.1, LS11.E, R15.2, U$1.45 (S16)
LS12: C9.1, LS12.E, R17.2, U$1.40 (S32)
LS13: C10.1, LS13.E, R19.2, U$1.39 (S31)
LS14: C11.1, LS14.E, R21.2, U$1.38 (S30)
LS15: C12.1, LS15.E, R23.2, U$1.37 (S29)
LS16: C17.1, LS16.E, R33.2, U$1.36 (S28)
LS17: C18.1, LS17.E, R35.2, U$1.35 (S27)
LS18: C19.1, LS18.E, R37.2, U$1.34 (S26)
LS19: C20.1, LS19.E, R39.2, U$1.33 (S25)
LS20: C21.1, LS20.E, R41.2, U$1.32 (S24)
LS21: C22.1, LS21.E, R43.2, U$1.31 (S23)
LS22: C23.1, LS22.E, R45.2, U$1.30 (S22)
LS23: C24.1, LS23.E, R47.2, U$1.29 (S21)
LS24: C25.1, LS24.E, R49.2, U$1.28 (S20)
LS25: C26.1, LS25.E, R51.2, U$1.27 (S19)
LS26: C27.1, LS26.E, R53.2, U$1.26 (S18)
LS27: C28.1, LS27.E, R55.2, U$1.25 (S17)
LS28: C29.1, LS28.E, R57.2, U$1.12 (S1)
LS29: C30.1, LS29.E, R59.2, U$1.11 (S2)
LS30: C31.1, LS30.E, R61.2, U$1.10 (S3)
LS31: C32.1, LS31.E, R63.2, U$1.9 (S4)
LS32: C33.1, LS32.E, R65.2, U$1.8 (S5)
LS33: C34.1, LS33.E, R67.2, U$1.7 (S6)
LS34: C35.1, LS34.E, R69.2, U$1.6 (S7)
LS35: C36.1, LS35.E, R71.2, U$1.5 (S8)
MUX_OUT: JP1.15, U$1.43 (D)
unnamed: D2.A, R4.1
unnamed: D1.A, R2.1
unnamed: D3.A, R6.1
unnamed: D4.A, R8.1
unnamed: D5.A, R10.1
unnamed: D6.A, R12.1
unnamed: D7.A, R14.1
unnamed: D8.A, R16.1
unnamed: D9.A, R18.1
unnamed: D10.A, R20.1
unnamed: D11.A, R22.1
unnamed: D12.A, R24.1
unnamed: D13.A, R26.1
unnamed: D14.A, R28.1
unnamed: D15.A, R30.1
unnamed: D16.A, R32.1
unnamed: D17.A, R34.1
unnamed: D18.A, R36.1
unnamed: D19.A, R38.1
unnamed: D20.A, R40.1
unnamed: D21.A, R42.1
unnamed: D22.A, R44.1
unnamed: D23.A, R46.1
unnamed: D24.A, R48.1
unnamed: D25.A, R50.1
unnamed: D26.A, R52.1
unnamed: D27.A, R54.1
unnamed: D28.A, R56.1
unnamed: D29.A, R58.1
unnamed: D30.A, R60.1
unnamed: D31.A, R62.1
unnamed: D32.A, R64.1
unnamed: D33.A, R66.1
unnamed: D34.A, R68.1
unnamed: D35.A, R70.1
unnamed: D36.A, R72.1
WR: JP1.14, U$1.21 (WR)



Board: 2 copper layers, 112.3 x 112.3 mm, 184 parts (181 on the bottom side), 83 nets.

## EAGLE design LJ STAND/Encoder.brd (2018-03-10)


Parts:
C1: 0.1uF; 0603-CAP
IC1, IC2: A1301LH; SOT23-W
J1: B4B-PH-K-S
R1, R2: 10K; 0603-RES

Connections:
GND: C1.2, IC1.3 (GND), IC2.3 (GND), J1.1
OUTA: IC1.2 (OUT), J1.3, R1.1
OUTB: IC2.2 (OUT), J1.2, R2.1
VCC: C1.1, IC1.1 (VCC), IC2.1 (VCC), J1.4, R1.2, R2.2


Board: 2 copper layers, 22.0 x 15.0 mm, 6 parts (1 on the bottom side), 4 nets.

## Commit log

2018-02-21 Initial commit - added encoder PCB
    [Encoder.brd, Encoder.sch]
2018-02-21 File saves
    [Encoder.brd]
2018-02-28 Main & light schematics, preliminary board layout
    [Encoder.brd, Encoder.sch, Light.brd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]
2018-03-01 Light PCB routing
    [Light.brd, Light.sch, Main.brd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]
2018-03-05 Finished routing light & encoder pcbs
    [Encoder.brd, Encoder.sch, Light.brd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]
2018-03-06 Main PCB routing
    [Gyro.brd, Gyro.sch, Main.brd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]
2018-03-07 Finished routing main pcb
    [Main.brd, Main.sch]
2018-03-07 Some small fixes to the main pcb
    [Main.brd, Main.sch]
2018-03-07 Light gate plug labels
    [Main.brd, Main.sch]
2018-03-08 Main edits, light gate pcbs
    [Encoder.brd, Gyro.brd, Laser Mount.brd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]
2018-03-10 Finalisation of gyro, encoder and light boards + gerbers, silkscreen fixes
    [Encoder.brd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]
2018-03-16 Pin changes on teensys, removed some screen pins for motor grounding
    [Encoder.DRL, Encoder.GBL, Encoder.GBO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]
2018-03-17 Small fixes incl. grounding
    [Main.brd, Main.sch]
2018-03-17 Final changes to main
    [Main.brd, Main.sch]
2018-03-17 Final main + gerbers
    [Main.DRL, Main.GBL, Main.GBO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]
2018-04-06 Gyro MPU9250 boards
    [Gyro MPU9250.brd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]

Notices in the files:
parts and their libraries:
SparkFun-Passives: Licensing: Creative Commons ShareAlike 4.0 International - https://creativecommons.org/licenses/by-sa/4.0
